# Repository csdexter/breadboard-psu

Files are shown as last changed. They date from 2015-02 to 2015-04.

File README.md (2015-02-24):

#Breadboard PSU#

(C) 2015 Radu - Eosif Mihailescu <radu.mihailescu@linux360.ro>

All files in this repository are licensed under the
**GNU Generic Public License v3**, a copy of whose text can be accessed
 [here](http://www.gnu.org/licenses/gpl.html).

This repository contains [EDA](http://en.wikipedia.org/wiki/Electronic_design_automation) source files for all of the boards in this project in CadSoft Eagle 7 format. Only the `.SCH` (schematic) and `.BRD` (board) files are provided as all data needed for manufacturing can easily be derived from the former. No guarantee is made as to which minor version of Eagle was used to save the file, but it *may* be the latest at the time of this writing.

The board description files *may* contain routing information or be supplied unrouted. In the former case, the routing artwork *may* have been generated by either Eagle's internal autorouter or [FreeRouting](http://www.freerouting.net/). A 25mil routing grid and 10/10mil trace/space settings will have been used in both cases.

All files included here are compatible with the free version of Eagle (i.e. describe PCBs having no more than 2 layers and measuring no more than 10cm by 8cm each).

Git tags will be used to mark specific revisions that were actually manufactured so that a correspondence between the evolution of the sources and the status of physical by-products can be maintained.

##WARNING##
*Unless and until explictily noted otherwise, the engineering materials here are laboratory quality and neither intended for manufacturing in production quantities nor for distribution (e.g. as kits) to end-users. The design data here does not explicitly follow any widely-accepted safety/security/EMI regulation or standard, therefore any manufacturing and/or usage in connection with live equipment is entirely at your own risk.*

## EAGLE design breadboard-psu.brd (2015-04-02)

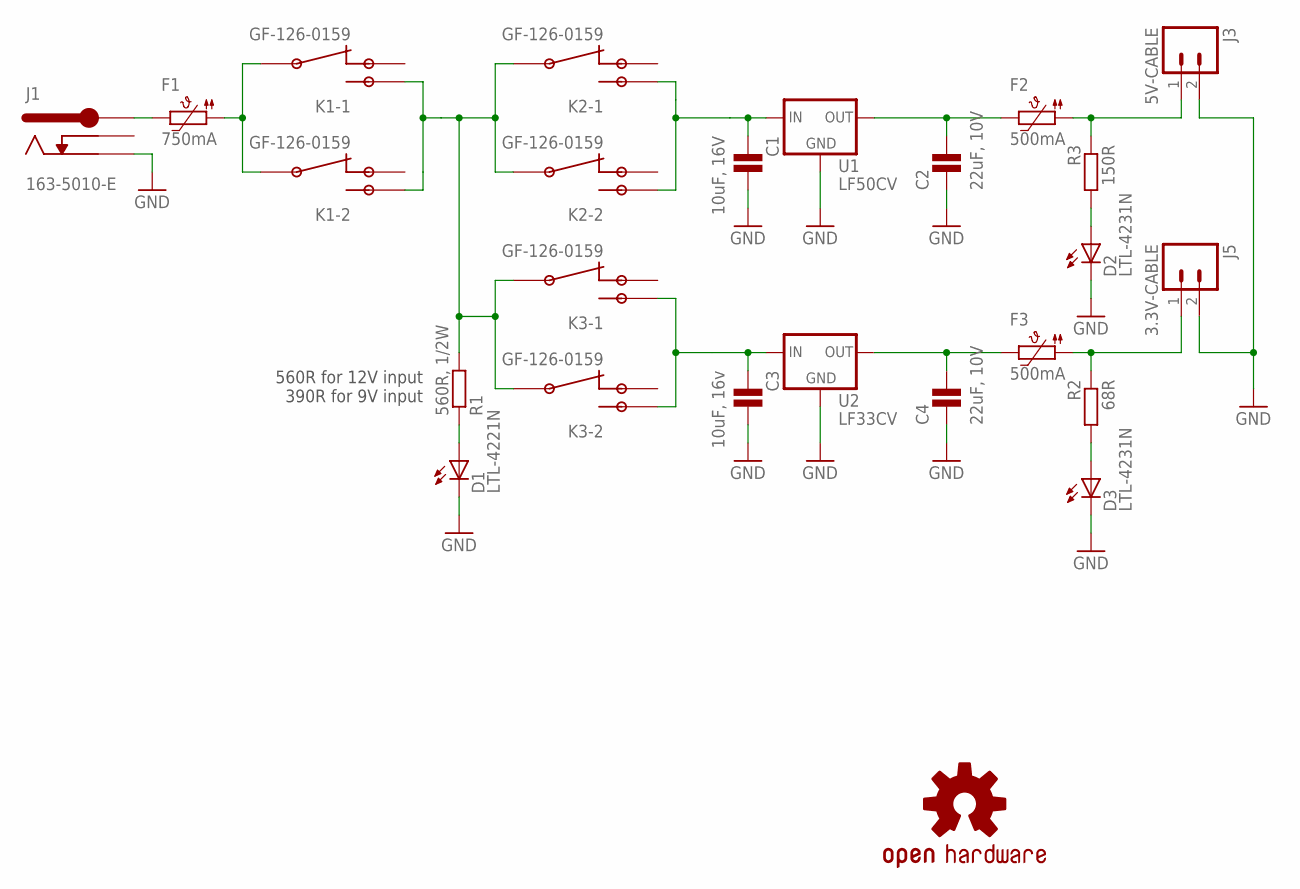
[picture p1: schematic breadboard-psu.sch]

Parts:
C1: 10uF, 16V; FK26*
C2, C4: 22uF, 10V; FK20*
C3: 10uF, 16v; FK26*
D1: LTL-4221N; LED3MM
D2, D3: LTL-4231N; LED3MM
F1: 750mA; AXIAL__GENERIC_10X3
F2, F3: 500mA; AXIAL__GENERIC_10X3
J1: 163-5010-E; 163-501*-E
J3: 5V-CABLE; MOLEX-1X2
J5: 3.3V-CABLE; MOLEX-1X2
K1, K2, K3: GF-126-0159
LOGO2: OSHW-LOGOL; OSHW-LOGO-L
R1: 560R, 1/2W; 0204V
R2: 68R; 0204V
R3: 150R; 0204V
U1: LF50CV; TO220-IGO
U2: LF33CV; TO220-IGO

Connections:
3V3: F3.P$1 (1), J5.1, R2.1
5V: F2.P$1 (1), J3.1, R3.1
GND: C1.P$2, C2.P$1, C3.P$2, C4.P$1, D1.K (C), D2.K (C), D3.K (C), J1.P$1 (-), J3.2, J5.2, U1.GND, U2.GND
unnamed: F1.P$2 (2), J1.P$4 (+)
unnamed: F1.P$1 (1), K1.P$2, K1.P$5
unnamed: K1.P$3, K1.P$6, K2.P$2, K2.P$5, K3.P$2, K3.P$5, R1.2
unnamed: C1.P$1, K2.P$3, K2.P$6, U1.IN
unnamed: C3.P$1, K3.P$3, K3.P$6, U2.IN
unnamed: C2.P$2, F2.P$2 (2), U1.OUT
unnamed: C4.P$2, F3.P$2 (2), U2.OUT
unnamed: D1.A, R1.1
unnamed: D2.A, R3.2
unnamed: D3.A, R2.2

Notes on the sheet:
560R for 12V input 390R for 9V input

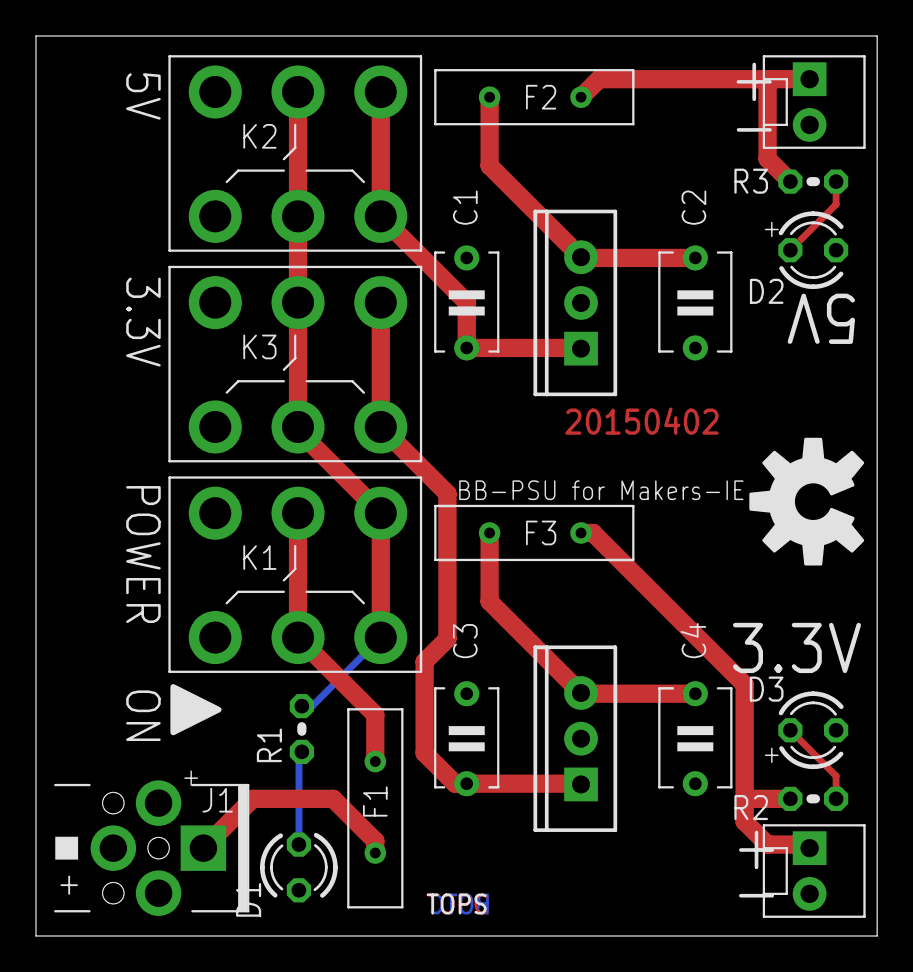
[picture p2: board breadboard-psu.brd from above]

Board: 2 copper layers, 46.7 x 50.0 mm, 22 parts (0 on the bottom side), 13 nets.

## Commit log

2015-02-21 Initial commit: - SCH and BRD in Eagle 7 - distance between fangs not proven yet, educated guess used - PCB is not finalized, still missing some footprints
    [breadboard-psu.brd, breadboard-psu.sch]
2015-02-21 UPDATE: - first draft, schematic is stable, layout is routed and poured. - still left to do the silkscreen and confirm width (to match breadboard). - all footprints checked or generated in-situ to ma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
    [breadboard-psu.brd, breadboard-psu.sch]
2015-02-23 UPDATE: - redesigned without fangs as various breadboards have various widths, leaving just cable version in - this allows us to fit in 5x5cm with drastic reduction in price
    [breadboard-psu.brd, breadboard-psu.sch]
2015-02-24 UPDATE: - PCB done, including silk, aesthetics, physicals and design for manufacturing - this is ready to go to the fab.
    [breadboard-psu.brd, breadboard-psu.sch]
2015-02-25 UPDATE: - forgot to put OSHW logo in schematic in the frame documentation box, where it belongs - added gerbv project file to aid offline viewing of manufacturing data - added Eagle3D custom mapping 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
    [breadboard-psu.brd, breadboard-psu.sch]
2015-04-02 Adjustments after the trial fab run: - enlarged in X dimension, still fits in 5x5cm - moved power LED behind DC jack, better contrast and visibility - enlarged legend text for switches and added sign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
    [breadboard-psu.brd, breadboard-psu.sch]

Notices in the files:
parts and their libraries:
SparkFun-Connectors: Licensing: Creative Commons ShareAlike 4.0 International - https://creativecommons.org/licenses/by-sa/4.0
